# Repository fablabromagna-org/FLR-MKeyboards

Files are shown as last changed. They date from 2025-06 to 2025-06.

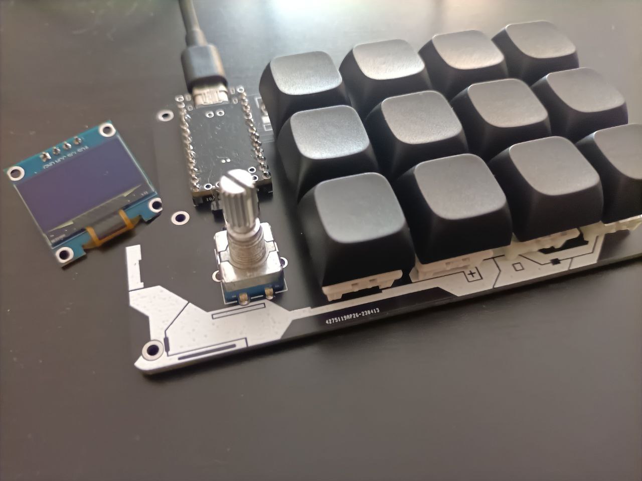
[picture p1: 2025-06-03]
khor_r12/images/r12.jpg

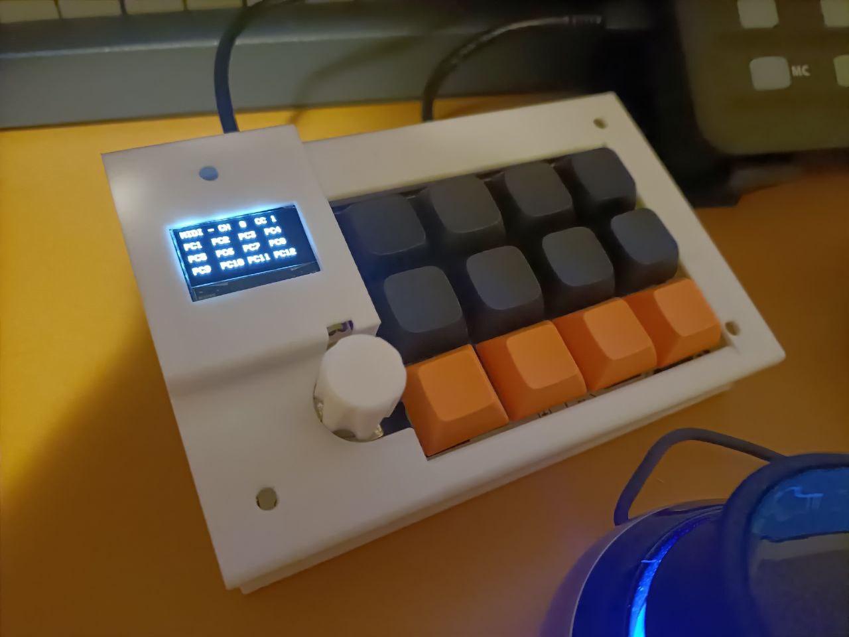
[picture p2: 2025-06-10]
khor_r12/3Dfiles/khor_case_it01/img1.jpg

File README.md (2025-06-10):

# FLR-MKeyboards

Progetti di tastiere meccaniche FablabRomagna

## Tastiere

- [Khor R12](khor_r12/) - Keypad 4x3 + Encoder +  I²C Oled Display 
## Organizzazione del repository

Questo repository contiene informazioni, documentazione e progetti di tastiere meccaniche (complete o keypad) utilizzate da FablabRomagna nell'ambito delle attività laboratoriali e di corsi.

Queste tastiere meccaniche, basate su microcontrollori di vario genere e firmware open source (es. QMK ma non solo) utilizzano tasti meccanici e schemi elettrici tipicamente gestiti a matrice.

Il repository è organizzato con un'area comune, contenente informazioni e risorse generiche e comuni alla costruzione e gestione di varie tastiere meccaniche, e di una serie di sottodirectory, una per ogni tipologia di tastiera.

Ogni sottodirectory contiene un file README che ne descrive le caratterisctiche e tutte le informazioni e i files per tale tastiera. Ed eventualmente una directory "firmware" contente le customizzazioni QMK (o altri) e relative istruzioni.

```
README.md
docs/
images/
<keyboardXYZ>/
    README.md
    docs/
    images/
    pcb/
    3Dfiles/
    firmware/

```

## Partecipazione al repository

> regole in via di definizione (soggette a possibili integrazioni)

E' possibile partecipare al progetto del presente repository in 2 modi:

1. eseguendo il fork del repository con il proprio account GitHub, eseguendo le modifiche su un branch separato, e poi eseguendo una pull request per integrare le proprie modifiche in questo repository (è il workflow classico promosso da GitHub - [istruzioni](https://docs.github.com/en/get-started/exploring-projects-on-github/contributing-to-a-project))
2. se sei un membro attivo di FablabRomagna puoi richiedere l'accesso al presente repository comunicando il tuo account GitHub a github@fablabromagna.org o tramite il canale Telegram dell'associazione

In quest'ultimo caso sarai abilitato ad eseguire push direttamente in questo repository, senza necessità di creare un fork.

Dovrai però seguire queste regole, per evitare conflitti sulle parti condivise:
- lavora sempre su un branch separato, e non in `main`. Sarebbe opportuno nominare i propri branch con un prefisso che indichi il nome del proprietario
- ove possibile, evita di modificare files o directory giá creati da altri; salvo concordarne le modifiche sul gruppo. Ad esempio, piuttosto che editare un keymap giá presente, creane uno tuo con un nome diverso
- mantieni le tue modifiche il piú possibile circoscritte ad una funzionalitá specifica. Se necessario crea piú branch personali (_questo perché i merge nel ramo `main` vengono eseguiti in toto sull'intero branch personale, e non per singoli files_)
- una volta completate le tue modifiche, richiedi agli amministratori del repository di integrarle (merge nel branch `main`)

> queste sono regole di massima per permetterci di tenere ordinato il repository lavorandoci a piú mani, ma possono ovviamente essere migliorate e cercheremo di gestire i contributi con flessibilitá

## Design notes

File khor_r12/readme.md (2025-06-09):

# Khor R12 

Keypad 4x3 con Encoder e Oled fornita da  [Khor](https://github.com/MoltenKhor/R12) ed utilizzata per la prima volta nel corso sulle tastiere meccaniche presso SanLab (maker space Santarcangelo di Romagna) del 22/05/2025, tenuto da  Giulio e Andrea.

## Descrizione HW

Il  **Keypad R12** é costituito da:
- 4x3 Matrix Switch 
- Encoder con pulsante
- I²C Oled Display

Utilizza una board  **Helios** basata su microcontrollore **RP2040**.

La matrice 4x3 e il pulsante dell'encoder utilizzano i pins descritti nel file `keyboard.json`.

```
/*
      * Matrix Layout and Pinout *
     
            GP22 GP26 GP27 GP28    GP29
           ┌────┬────┬────┬────┬──────────────┐
      GP7  │  0 │  1 │  2 │  3 │ EncoderSwitch│
           ├────┼────┼────┼────┼──────────────┤ 
      GP8  │  4 │  5 │  6 │  7 │    n.c.
           ├────┼────┼────┼────┤
      GP9  │  8 │  9 │ 10 │ 11 │    n.c.
           └────┴────┴────┴────┘
           
*/
``` 

> Il pulsante dell'encoder usa i pin GP29 e GP7, quindi puó essere usato nel controller della matrice come un normale switch della tastiera

L'encoder é collegato direttamente ai pins GP6 and GP5.

Il display OLED I²C é collegato ai pins SDA/SCL (GP6, GP5).

## Firmware

Al momento i test e le personalizzazioni sono state fatte con il firmware [QMK](https://github.com/qmk/qmk_firmware).

Le diverse implementazioni e le istruzioni per la compilazione sono sono disponibili nella sezione `firmware`, all'interno della cartella [fablabromagna](firmware/keyboards/fablabromagna/r12_it)

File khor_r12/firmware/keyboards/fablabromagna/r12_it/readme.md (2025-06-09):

# Khor R12 firmware 

> 2025 Ivan (itarozzi - ivan.tarozzi@fablabromagna.org)

Firmware QMK basato sul lavoro di [Khor](https://github.com/MoltenKhor/R12).

Rispetto al firmware Khor sono state apportate le seguenti modifiche:

- aggiunto pulsante dell'encoder nel file `keyboard.json`
- aggiunta la gestione dell'encoder (rotazione)
- aggiunta la gestione del display OLED 
- creato una serie di keymaps per diversi ambiti operativi

I vari keymaps sono disponibili nella cartella [keymaps](./keymaps/) :

### Oled

Integrazione base del display OLED con la semplice visualizzazione del logo QMK.

### Encoder

Integrazione base dell'encoder e del relativo pulsante (come tredicesimo switch).

Inoltre questo esempio implementa la gestione di 2 layer. L'accesso al layer 2 viene eseguito con la pressione del pulsante dell'encoder.

Il layer attivo viene visualizzato sul display.

### App_Keypad

Questo keymap ha lo scopo di realizzare un keypad per l'invio di  shortcut funzionanti con diverse applicazioni.

Per ogni applicazione é possibile definire diversi shortcut, corrispondenti a diversi eventi sui 12 pulsanti e sull'encoder.

Ogni applicazione puó inoltre disporre di vare sotto-modalitá di lavoro, ognuna con i propri shortcut specifici.

Un OLED di dimensioni maggiori rispetto a quello previsto da Khor viene usato per mostrare l'applicazione selezionata e un reminder per le funzioni legate ai 12 tasti.

Maggiori informazioni nel [file readme](./keymaps/app_keypad/readme.md) relativo.

## Come compilare il firmware QMK

1. installare e configurare l'ambiente di compilazione del firmware QMK per il proprio sistema operativo, seguendo le istruzioni indicate qui: [https://docs.qmk.fm/newbs_getting_started](https://docs.qmk.fm/newbs_getting_started)
2. copiare il contenuto della directory `khor_r12/firmware/keyboards/fablabromagna` all'interno del ramo del progetto QMK, nella directory `<qmk_firmware>/keyboards`
3. compilare il firmware specificando il nome della keyboard `fablabromagna/r12_it` e il keymap desiderato tra quelli presenti (corrisponde al nome della directory sotto `keymaps`)

Esempi:

```
qmk compile -kb fablabromagna/r12_it  -km oled

qmk compile -kb fablabromagna/r12_it  -km encoder

qmk compile -kb fablabromagna/r12_it  -km app_keypad 
```

> utilizzando per la compilazione un sistema Linux è possibile creare un link simbolico che dalla directory dei sorgenti QMK punti alla directory `fablabromagna` di questo repository. In questo modo sará possibile lavorare direttamente sul repository git FLR-MKeyboards senza preoccuparsi di copiare ogni volta i files aggiornati nella cartella del firmware QMK, e gestendo il versioning tramite Git.

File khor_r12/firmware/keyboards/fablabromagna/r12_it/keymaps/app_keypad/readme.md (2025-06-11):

# Khor R12 firmware - AppKeypad

> 2025 Ivan (itarozzi - ivan.tarozzi@fablabromagna.org)

Firmware QMK basato sul lavoro di [Khor](https://github.com/MoltenKhor/R12).

Implementa un keypad per la gestione di applicazioni multiple.

## L'idea di keypad per applicazioni

Questa implementazione nasce con l'obiettivo di creare un tastierino per inviare shortcuts (tasti singoli o sequenze di tasti) a varie applicazioni (FreeCAD, Inkscape, OBS).  
Implementa inoltre anche un controller **MIDI**, per eventuali applicazioni che favoriscano l'integrazione con questo protocollo.  

E' possibile configurare diverse applicazioni, selezionabili con l'encoder:
- con la pressione prolungata si entra in modalità di _selezione applicazione_
- ruotando l'encoder si seleziona l'applicazione
- con una nuova pressione prolungata si esce dalla modalità di _selezione applicazione_

Ogni applicazione può disporre di più modalità operative (Mode default = 0). In questo modo è possibile creare dei layout diversi per le differenti modalità operative.  
Ad esempio per l'uso con FreeCAD sarà possibile definire un layout per la modalità _Part Design_, uno per la modalità _Sketch_ e così via.  

Al momento sono previste un massimo di 4 modalità per ogni applicazione, ma potrebbero essere ampliate.  

Per ogni modalità viene mostrato sul display un layout mnemonico con una stringa (max 3 caratteri) per ognuno dei 12 tasti.  

In ogni modalità, per ognuno dei 12 tasti, è possibile associare l'invio di shortcuts abbinati a vari eventi:  
- pressione singola
- pressione doppia 
- pressione prolungata

> E' possibile definire altre tipologie di eventi, sulla base della gestione del modulo **Tap Dance** di **QMK**: vedi [documentazione](https://docs.qmk.fm/features/tap_dance).

Solitamente, nei layout implmentati, la pressione prolungata dei tasti 9 - 12 permette di accedere alle 4 modalità (ove previste).  
E' possibile ridefinire questo comportamento, avendo cura di prevedere sempre un modo per tornare alla modalità iniziale o precedente.

Un file **.ods** allegato al presente progetto contiene un elenco delle varie modalità per ogni applicazione, con le funzioni associate ad ogni evento dei tasti. 

> Al momento solo un sottoinsieme dei layout contenuti nel file ods sono stati implementati

## Applicazioni e modi implementati

### Default

> descrizione da completare

### FreeCAD 

> descrizione da completare

### MIDI

Questa applicazione prevede per ora una sola modalità.   
La pressione sul tasto encoder permette di selezionare il canale MIDI. Ruotare per selezionare il canale. Premere nuovamente per confermare.

Le pressioni singole sui tasti 1-12 inviano un messaggio MIDI Program Change (PC) con valore da 1 a 12.

Le pressioni doppie sui tasti 1-12 selezionano il Control Change attivo (da 1 a 12).  

Ruotando l'encoder viene inviato un messaggio MIDI Control Change sul Control selezionato, con valore da 0 a 127.  

Canale e CC selezionati sono mostrati sul display.

> Nota: esiste al momento un offset indesiderato tra il canale MIDI selezionato/visualizzato e quello utilizzato in fase di invio del messaggio. Da verificare. 

## Aggiungere una nuova applicazione

> descrizione da completare

> Work in progress...

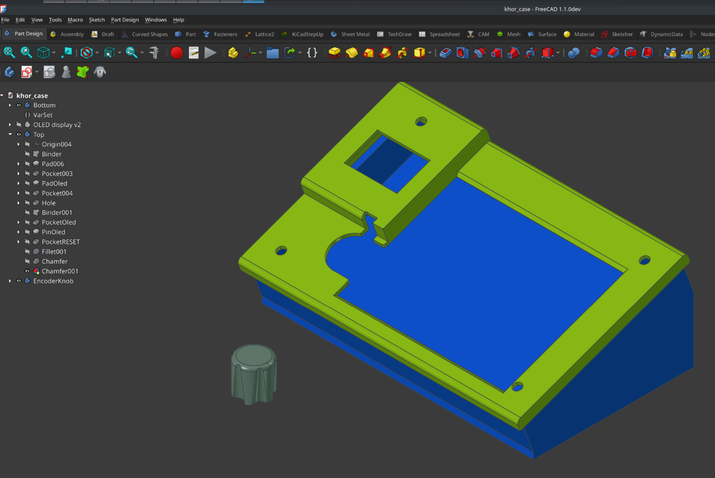
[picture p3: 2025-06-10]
khor_r12/3Dfiles/khor_case_it01/img_cad.png

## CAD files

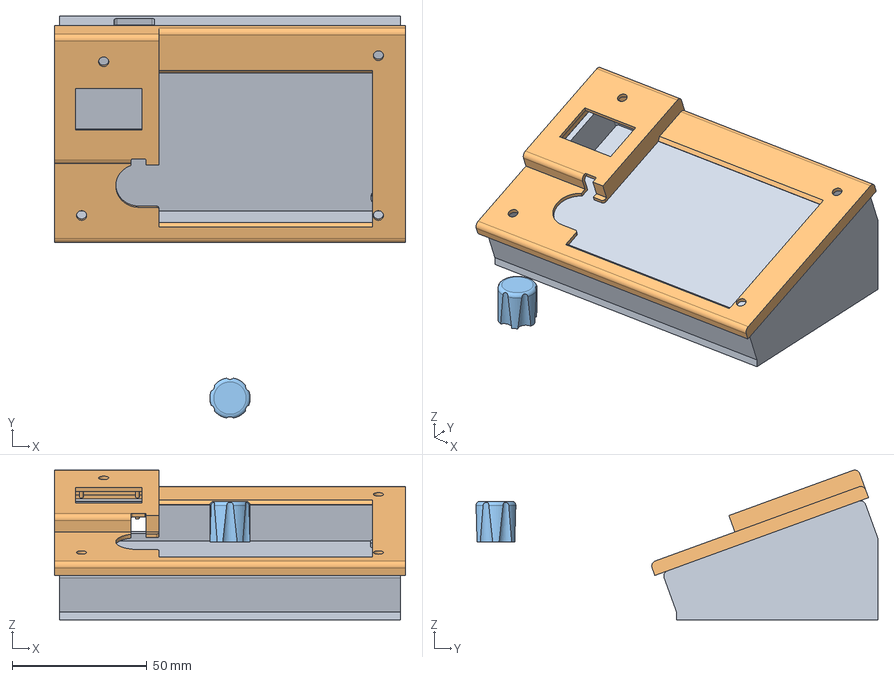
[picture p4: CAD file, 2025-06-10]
khor_r12/3Dfiles/khor_case_it01/khor_case_it01.FCStd
130.4 x 149.2 x 55.6 mm
Bottom
Top
EncoderKnob

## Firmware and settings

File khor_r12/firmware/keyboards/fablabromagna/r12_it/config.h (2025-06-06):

#pragma once

#define I2C_DRIVER I2CD1
#define I2C1_SDA_PIN GP2
#define I2C1_SCL_PIN GP3

#define I2C1_SCL_PIN GP3

#define OLED_DISPLAY_128X64

#define NUMBER_OF_ENCODERS 1

#define ENCODER_A_PINS { GP6 }
#define ENCODER_B_PINS { GP5 }

#define ENCODER_RESOLUTION 4
#define ENCODER_MAP_KEY_DELAY 10

#define MIDI_ADVANCED

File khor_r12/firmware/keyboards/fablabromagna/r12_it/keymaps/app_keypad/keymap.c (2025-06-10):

// Copyright 2023 QMK
// SPDX-License-Identifier: GPL-2.0-or-later


/* Application multimode 
 *
 * 2025 ivan.tarozzi@fablabromagna.org
 *
 * How to add an application keymap :
 *
 * 1. define a new enum item in application_ids
 * 2. add a new c file containing the app handler (see freecad_handler.c ad example)
 * 3. add the handler prototype to keys_definitions.h 
 * 4. add a new item to the applications[] array
 * 5. assign encoder actions in encoder_update_user() 
 * 6. print to OLED for each app mode in oled_task_user()
 *
 *
 * Usage:
 * - long-press the encoder switch to enter the app selection mode
 * - select the desired application keymap with encoder rotation
 * - confirm with long-press encoder switch
 * - alternate app mode are usually called long-pressing the buttons 9-12 (but you can define other methods in your handler file)
 * 
*/ 

#include QMK_KEYBOARD_H
#include "print.h"

#include "keys_definitions.h"







/*************************
 * APPLICATIONS MANAGEMENT
 **************************/
enum application_ids {
    _APP_DEFAULT,
    _APP_FREECAD,
    _APP_OBS,
    _APP_INKSCAPE
};


typedef struct {
    uint8_t appid;
    uint8_t  modes;
    char *display_name;  // max 10 chars
    return_selection_t (*handler_keypad)(uint8_t appid, uint8_t mode,uint8_t key_id, uint8_t tap_count, bool is_hold);
    bool (*handler_encoder)(uint8_t index, bool clockwise);
    bool (*handler_oled)(current_selection_t);

} application_t;


current_selection_t current_selection = {
    .selecting_app = false,
    .appid = _APP_DEFAULT,
    .mode = 0
};

application_t applications[] = {
    {_APP_DEFAULT, 1, APP_NAME_DEFAULT, handler_keypad_default, handler_encoder_default, handler_oled_default},
    {_APP_FREECAD, 2, APP_NAME_FREECAD, handler_keypad_freecad, handler_encoder_freecad, handler_oled_freecad},
    {_APP_FREECAD, 2, APP_NAME_MIDI, handler_keypad_midi, handler_encoder_midi, handler_oled_midi},
    // {_APP_OBS, 1, "OBS", NULL},
    // {_APP_INKSCAPE, 1, "INKSCAPE", NULL}
};




/*************************
 * TAP DANCE MANAGEMENT
 **************************/

// Enum for tap dance actions
enum tap_dance_keys {
    TD_KEY_1,
    TD_KEY_2,
    TD_KEY_3,
    TD_KEY_4,
    TD_KEY_5,
    TD_KEY_6,
    TD_KEY_7,
    TD_KEY_8,
    TD_KEY_9,
    TD_KEY_10,
    TD_KEY_11,
    TD_KEY_12,
    TD_KEY_ENCODER
};

// Tap dance states
enum tap_dance_states {
    TD_NONE,
    TD_UNKNOWN,
    TD_SINGLE_TAP,
    TD_SINGLE_HOLD,
    TD_DOUBLE_TAP,
    TD_DOUBLE_HOLD,
    TD_TRIPLE_TAP,
    TD_TRIPLE_HOLD
};

// Function to determine tap dance state
uint8_t cur_dance(tap_dance_state_t *state) {
    if (state->count == 1) {
        if (state->interrupted || !state->pressed) return TD_SINGLE_TAP;
        else return TD_SINGLE_HOLD;
    } else if (state->count == 2) {
        if (state->interrupted || !state->pressed) return TD_DOUBLE_TAP;
        else return TD_DOUBLE_HOLD;
    } else if (state->count == 3) {
        if (state->interrupted || !state->pressed) return TD_TRIPLE_TAP;
        else return TD_TRIPLE_HOLD;
    }
    return TD_UNKNOWN;
}


void handle_keypad_action(uint8_t key_id, uint8_t tap_count, bool is_hold);

// Your custom handler function - use macro to generate all callbacks
#define GENERATE_TD_CALLBACK(key_name, key_id) \
    void td_##key_name##_finished(tap_dance_state_t *state, void *user_data) { \
        uint8_t tap_state = cur_dance(state); \
        switch (tap_state) { \
            case TD_SINGLE_TAP: handle_keypad_action(key_id, 1, false); break; \
            case TD_SINGLE_HOLD: handle_keypad_action(key_id, 1, true); break; \
            case TD_DOUBLE_TAP: handle_keypad_action(key_id, 2, false); break; \
            case TD_DOUBLE_HOLD: handle_keypad_action(key_id, 2, true); break; \
            case TD_TRIPLE_TAP: handle_keypad_action(key_id, 3, false); break; \
            case TD_TRIPLE_HOLD: handle_keypad_action(key_id, 3, true); break; \
        } \
    }

// Generate all callback functions
GENERATE_TD_CALLBACK(key_1, KEY_1)
GENERATE_TD_CALLBACK(key_2, KEY_2)
GENERATE_TD_CALLBACK(key_3, KEY_3)
GENERATE_TD_CALLBACK(key_4, KEY_4)
GENERATE_TD_CALLBACK(key_5, KEY_5)
GENERATE_TD_CALLBACK(key_6, KEY_6)
GENERATE_TD_CALLBACK(key_7, KEY_7)
GENERATE_TD_CALLBACK(key_8, KEY_8)
GENERATE_TD_CALLBACK(key_9, KEY_9)
GENERATE_TD_CALLBACK(key_10, KEY_10)
GENERATE_TD_CALLBACK(key_11, KEY_11)
GENERATE_TD_CALLBACK(key_12, KEY_12)
GENERATE_TD_CALLBACK(key_encoder, KEY_ENCODER)



// Reset function for tap dance
void keypad_tap_dance_reset(tap_dance_state_t *state, void *user_data) {
    // Handle any cleanup needed when tap dance resets
    // For example, release held keys
    unregister_code(KC_LCTL); // Release any held modifiers
}

// macro to define tap dance actions
#define TD_ACTION(key_name) ACTION_TAP_DANCE_FN_ADVANCED(NULL, td_##key_name##_finished, keypad_tap_dance_reset)


tap_dance_action_t tap_dance_actions[] = {
    [TD_KEY_1] = TD_ACTION(key_1),
    [TD_KEY_2] = TD_ACTION(key_2),
    [TD_KEY_3] = TD_ACTION(key_3),
    [TD_KEY_4] = TD_ACTION(key_4),
    [TD_KEY_5] = TD_ACTION(key_5),
    [TD_KEY_6] = TD_ACTION(key_6),
    [TD_KEY_7] = TD_ACTION(key_7),
    [TD_KEY_8] = TD_ACTION(key_8),
    [TD_KEY_9] = TD_ACTION(key_9),
    [TD_KEY_10] = TD_ACTION(key_10),
    [TD_KEY_11] = TD_ACTION(key_11),
    [TD_KEY_12] = TD_ACTION(key_12),
    [TD_KEY_ENCODER] = TD_ACTION(key_encoder),
};

// Optional: Configure tap dance timing
uint16_t get_tapping_term(uint16_t keycode, keyrecord_t *record) {
    switch (keycode) {
        case TD(TD_KEY_1):
        case TD(TD_KEY_2):
        case TD(TD_KEY_3):
        case TD(TD_KEY_4):
        case TD(TD_KEY_5):
        case TD(TD_KEY_6):
        case TD(TD_KEY_7):
        case TD(TD_KEY_8):
        case TD(TD_KEY_9):
        case TD(TD_KEY_10):
        case TD(TD_KEY_11):
        case TD(TD_KEY_12):
            return 500;  // 500ms for tap dance timing
        default:
            return TAPPING_TERM;
    }
}


/**************************
 * The tap dance generic handler, where the magic happens :)
 **************************/
void handle_keypad_action(uint8_t key_id, uint8_t tap_count, bool is_hold) {
    return_selection_t ret_value;
    uprintf("key_id: %d, tap_count: %d, is_hold: %d\n", key_id, tap_count, is_hold);
    
    if  (key_id == KEY_ENCODER && tap_count == 1 && is_hold) {
        oled_clear();
        current_selection.selecting_app = !current_selection.selecting_app;
    }
    else {
        // TODO: check applications id range
        if (applications[current_selection.appid].handler_keypad != NULL) {
            ret_value = applications[current_selection.appid].handler_keypad(current_selection.appid, current_selection.mode, key_id, tap_count, is_hold);
            current_selection.appid = ret_value.appid;
            current_selection.mode  = ret_value.mode;
        }
    }            
}


/*************************
 * LAYERS MANAGEMENT
 **************************/
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

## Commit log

2025-06-03 commit iniziale con readme principale e keyboard Khor R12
    [R12KeypadConfiguration.ods]
2025-06-06 review degli handler, spostando anche quelli di encoder e oled nei files delle relative applicazioni
2025-06-06 aggiunto handler di default e implementato CC e PC su MIDI
2025-06-09 fix esempio oled e suddiviso il file rules.mk in 3 files, uno per ogni keymaps, con i soli moduli abilitati per il relativo esempio
    [keymap.c]
2025-06-09 aggiornato readme e aggiornato esempio encoder, con utilizzo del pulsante encoder come tredicesimo tasto
2025-06-10 Update README.md con le regole di partecipazione al progetto
2025-06-10 completato prima implementazione MIDI e vari fix su controllo OLED
    [R12KeypadConfiguration.ods]
2025-06-10 Aggiornato readme di descrizione del keymap app_keypad
2025-06-10 aggiunti files 3D FreeCAD e relative immagini
    [khor_case_it01.FCStd]
